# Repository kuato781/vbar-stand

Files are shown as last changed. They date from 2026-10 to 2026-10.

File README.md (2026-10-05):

# Folding Indexed Stand for the VBar Transmitter

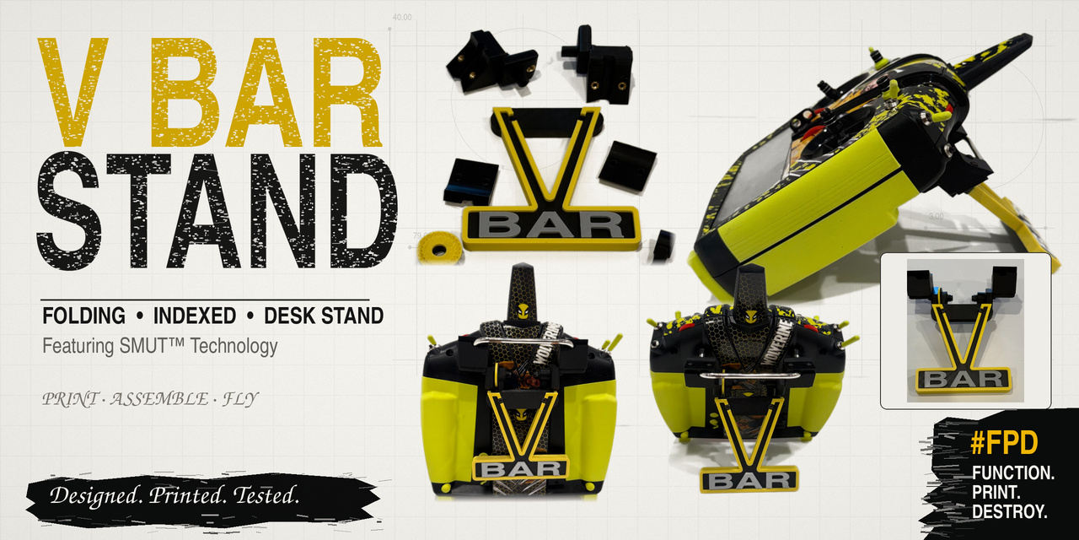
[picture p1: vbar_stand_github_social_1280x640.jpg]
VBar stand


A folding, indexed-position desk stand for the VBar transmitter's curved metal carrying handle. The handle clamps are shaped for this radio; the two retained pivots and right-side spring-ball detent follow the proven **SMUT™** (**S**ide **M**ount **U**nit **T**echnology) architecture from the [iX14](https://github.com/kuato781/spektrum-ix14-stand) and [Spirit WAVE](https://github.com/kuato781/spirit-wave-stand) stands.

The stand folds against the back of the transmitter, keeps the carrying handle usable, and indexes into position with a replaceable detent ring. It mounts without permanently modifying the radio.

## Start here

- [Assembly instructions](documentation/assembly-instructions/assembly-instructions.md)
- [Printable three-stage assembly guide](documentation/exploded-view/VBar-assembly-guide.pdf)
- [Hardware buy list](buy-list/VBar-Stand-Buy-List.md)
- [Bambu Studio notes](bambu-studio-3mf/bambu-studio-profile.md)
- [Individual STL and SCAD files](stl-scad/)
- [Product photos](documentation/product-images/)

Ready-to-slice Bambu Studio projects are available for the [mounting hardware](bambu-studio-3mf/mounting-hardware/Vbar_all_mounting_hardware.3mf) and the [three-color stand](bambu-studio-3mf/stand/VBar-Stand.3mf). The ten individual STLs are also in `stl-scad/`.

## The VBar-specific fit

The handle rises at an unusual angle, so both case bodies and their matching caps follow the measured handle path. The channel was adjusted during physical fitting until the two sides held the stand square to the transmitter. The final clamp has a left and a right body **and** a left and a right cap; these are not interchangeable common caps.

**Left and right mean looking at the front of the radio.** A shallow `L` or `R` is etched into each matching case/cap. Those letters face **inward toward the middle of the handle** when installed.

The stand/header uses **40 mm pivot-mount centers**, a keyed block at each pivot, and a 66 × 18 × 7 mm header envelope. The replaceable detent ring and M4 spring-loaded ball plunger are on the **right** side.

The V/BAR stand is split into three aligned color parts:

1. `VBar-SMUT-Stand-HEADER-CORE.stl` - structural core and header;
2. `VBar-SMUT-Stand-WRAP.stl` - raised V and outside-edge wrap;
3. `VBar-SMUT-Stand-BAR.stl` - raised BAR lettering.

The pictured build uses a black core, yellow V/wrap, and silver BAR lettering. Import the three STLs **together as parts of one object at their shared origin** if building your own multicolor slice. The header is already included in the core; it is not an extra print.

## Important assembly notes

- Use **four M3 × 10 mm cap screws** (two per side). The Spirit WAVE instructions' M3 × 12 mm length does not apply here.
- Apply a **thin strip of double-sided tape to the tops of the handle** at the clamp locations before fitting the caps. Keep it narrow and away from the controls. The tested build used this to remove a little wiggle.
- Snug the cap screws enough to locate the clamps. The case/cap assemblies can still feel loose at this stage; the keyed stand/header squares and locks the two sides together.
- While tightening the stand mounting screws, **push the stand downward** so the header clears the lower corner of each case. Cycle the full folding motion afterward and confirm clearance on both sides.
- A visible gap at the cap/body seam is expected. Clamp securely without trying to force the halves flush.

The [assembly instructions](documentation/assembly-instructions/assembly-instructions.md) give the full sequence, insert locations, pivot hardware, and plunger adjustment.

## Product photos

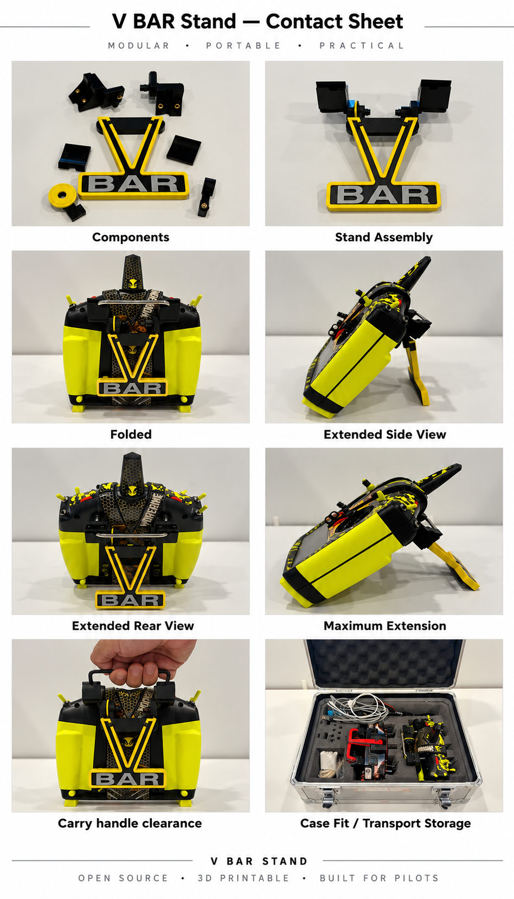
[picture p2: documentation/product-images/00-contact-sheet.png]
VBar stand parts and completed assembly


These are photographs of the actual printed parts and radio: [components](documentation/product-images/01-components.jpg), [assembled](documentation/product-images/02-assembled.jpg), [folded](documentation/product-images/03-folded.jpg), [extended](documentation/product-images/05-extended.jpg), and [mechanical clearance](documentation/product-images/08-clearance.jpg). Additional side and transport views are in the [product-image directory](documentation/product-images/).

## Print files and source

The mounting-hardware 3MF and stand 3MF are separate so each can be printed or reprinted independently. The stand 3MF preserves the aligned multicolor parts. Review printer, build plate, material mapping, orientation, and sliced preview before printing.

Each final STL has a matching SCAD in `stl-scad/`. The SCAD files default to the exact final mesh. The three stand pieces additionally share editable OpenSCAD dimensions in `_vbar_stand_geometry.scad`; the clamp/pivot pieces are mesh-backed because the final case bodies combine measured clamp geometry with remeshed donor pivots. See [SCAD and STL notes](stl-scad/README.md) for what can be changed natively and for the original CadQuery build source.

The development loop was **measure → model → print → fit → revise**. The final parts shown here were physically printed and fitted. PETG was used for the documented build; verify your own prints, hardware and motion before relying on them.

## Repository map

| Path | Contents |
| --- | --- |
| `bambu-studio-3mf/` | Prepared mounting-hardware and multicolor stand projects, plus print notes |
| `buy-list/` | Inserts, screws, plunger, and other assembly supplies |
| `documentation/assembly-instructions/` | Detailed assembly sequence |
| `documentation/exploded-view/` | Printable three-stage guide and page images |
| `documentation/product-images/` | Photos of the physical build |
| `stl-scad/` | Ten final STL/SCAD pairs, stand assembly preview and source notes |

## Safety, affiliation and license

This is a desk/simulator stand, **not a replacement carrying handle**. Inspect parts, heat-set inserts and screws regularly, and confirm motion and stability before use. Read the [disclaimer](DISCLAIMER.md).

This independent community project is not affiliated with or endorsed by Mikado Model Helicopters. VBar and associated names and marks identify the compatible transmitter and remain with their respective owners.

The files are shared under [Creative Commons Attribution-NonCommercial 4.0 International](LICENSE): noncommercial copying, printing and modification with attribution and identification of changes. Commercial use requires separate permission from the creator.

AI assisted with the modeling and documentation through many print-and-fit iterations. The printer and the actual radio got the final vote. :-)

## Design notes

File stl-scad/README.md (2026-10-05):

# Final VBar STL and SCAD Parts

The ten final STL files and ten same-name SCAD files sit side by side in this directory. Open the SCAD in OpenSCAD from a downloaded copy of the entire directory so its neighboring STL resolves by relative filename. The stand preview and `_vbar_stand_geometry.scad` are additional source/helper files.

| Part group | Files | Notes |
| --- | --- | --- |
| Handle clamp | Left/right body and matching left/right cap | Four separate parts; shallow `L`/`R` marks face inward on the radio |
| Pivot mechanism | Left/right pivot stub and detent ring | Ring and spring-ball detent are on the right |
| V/BAR stand | HEADER-CORE, WRAP, BAR | Import all three STLs at one shared origin for color printing |

All per-part SCAD files load their **exact final STL by default**. The three stand SCADs can also generate an editable OpenSCAD reconstruction: set `exact_mesh=false` and change dimensions in `_vbar_stand_geometry.scad`. Font shaping and offset tessellation may differ from the fit-tested STL, so validate a regenerated part before printing it.

The clamp bodies were built from a measured handle path joined to the proven pivot donor with voxel mesh operations. The stubs and ring are carried-forward donor meshes. Their SCADs contain `add_material()` and `remove_material()` hooks for local boolean changes to the exact final mesh; their base shapes are not fully parametric OpenSCAD primitives. This distinction is deliberate.

The [stand assembly preview](VBar-SMUT-stand-assembly-preview.scad) displays the three aligned parts in color. For printing, use the individual STLs or the prepared [stand 3MF](../bambu-studio-3mf/stand/VBar-Stand.3mf). Do not import the three STLs as independently centered objects.

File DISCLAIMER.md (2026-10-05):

# Use at Your Own Risk

The models, print profiles, instructions, photos and other materials in this repository are provided for personal, noncommercial use **as is**. No warranty or representation is made that they are accurate, complete, safe, suitable for a particular purpose or compatible with a particular printer, material or transmitter revision.

3D-printed parts vary with calibration, filament, slicer settings, print orientation, layer bonding, heat-set technique, fastener tolerances, use and wear. Review the files and hardware; inspect every print and insert; verify fit and pivot motion on your own radio; test on a stable surface; and reinspect the assembly periodically. Replace cracked, deformed or worn parts.

This is a desk/simulator stand, **not a replacement carrying handle**. The installed stand changes the radio's external dimensions; check any transport case for clearance before closing it. Never force a fold, pivot or latch through an obstruction. Independently verify anything that could affect control or safe operation of the transmitter.

By downloading, printing, modifying, assembling or using these materials, you accept the associated risks, including damage to equipment or property and personal injury. The parts are not professionally engineered, certified or tested as safety equipment. To the maximum extent permitted by law, the creator and contributors are not liable for losses arising from their use or inability to be used.

If you modify or redistribute the files, identify your changes and validate your version. Preserve this disclaimer or provide an equivalent notice. This independent project is not affiliated with or endorsed by Mikado Model Helicopters; VBar and related names and marks remain with their respective owners.

This disclaimer supplements the [LICENSE](LICENSE); if they conflict, the license controls.

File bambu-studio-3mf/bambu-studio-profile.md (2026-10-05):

# Bambu Studio Notes - VBar Stand

The repository contains separate prepared projects:

- [Vbar_all_mounting_hardware.3mf](mounting-hardware/Vbar_all_mounting_hardware.3mf)
- [VBar-Stand.3mf](stand/VBar-Stand.3mf)

The mounting hardware can be reprinted independently of the three-color stand. The documented physical build uses PETG. Choose a suitable PETG profile for your printer and filament, then verify the selected machine, plate, nozzle and filament mapping before slicing.

## Stand color parts

The stand comprises three aligned objects: black structural core/header, colored V and edge wrap, and BAR lettering. The photographed build uses yellow for the wrap and silver for the letters. Preserve their shared origin when importing the individual STLs; do not center each part separately.

The black core already includes the keyed header. The stand project is the simplest way to retain the intended color separation.

## Before printing

- Inspect the sliced preview for missing regions, unexpected supports, color changes and gaps.
- Confirm that cap holes, pivot sleeves, keyed blocks and the M4 plunger insert bore print cleanly.
- Confirm that the stand's black core, V wrap and letters remain aligned.
- Check the 3MF's material mapping and printer settings against your own setup; do not assume those settings transfer automatically.

## Fit-sensitive details

- Left/right case bodies and caps are distinct. Their shallow `L` and `R` marks face the inside of the handle when viewed from the front of the radio.
- Use the VBar's **M3 × 10 mm cap screws**.
- A thin double-sided tape strip on top of the handle helps remove play before the caps are fitted.
- The clamped halves can feel a little loose until the stand/header joins and squares both sides. A small cap/body gap is expected.
- During final tightening, press the stand downward to ensure its header clears the bottom case corners, then cycle the full range of motion.

Follow the [assembly instructions](../documentation/assembly-instructions/assembly-instructions.md) and verify the fit of your printed parts on your own radio.

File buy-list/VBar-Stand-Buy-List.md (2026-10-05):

# VBar Stand - Hardware Buy List

This VBar implementation uses the retained-pivot and detent hardware proven on the iX14 and Spirit WAVE stands, with **M3 × 10 mm cap screws** for the VBar-specific clamps.

## Heat-set inserts

- [ ] **6 × M3 inserts**, approximately **5 mm outside diameter × 5 mm long** - four in the case bodies for cap screws, one in each pivot-stub stand block
- [ ] **1 × M4 insert**, approximately **6 mm outside diameter × 6 mm long** - right case body for the ball plunger

## Pivot and detent hardware

- [ ] **1 × M4 × 0.7 spring-loaded ball plunger**, approximately 8-9 mm threaded body with an approximately 2.5 mm ball (tested spring range: 3-15 N)
- [ ] **2 × M4 × 20 mm socket-head or button-head screws**
- [ ] **2 × M4 Nyloc nuts**
- [ ] **2 × M4 flat washers**

## Clamp and stand hardware

- [ ] **4 × M3 × 10 mm socket-head or button-head screws** - two for each case cap
- [ ] **2 × M3 × 8 mm button-head screws** - keyed stand/header mounts
- [ ] **2 × M3 flat washers** - stand mounting screws

## Assembly supplies

- [ ] **Thin double-sided tape**, one narrow strip on top of the handle at each clamp location
- [ ] Optional: a small amount of **removable, non-permanent threadlocker** for the ball-plunger threads

The two caps are different left/right parts. A shallow `L`/`R` on each cap and body faces inward when mounted, as seen from the front of the radio. Do not substitute the Spirit WAVE's M3 × 12 mm cap screws.

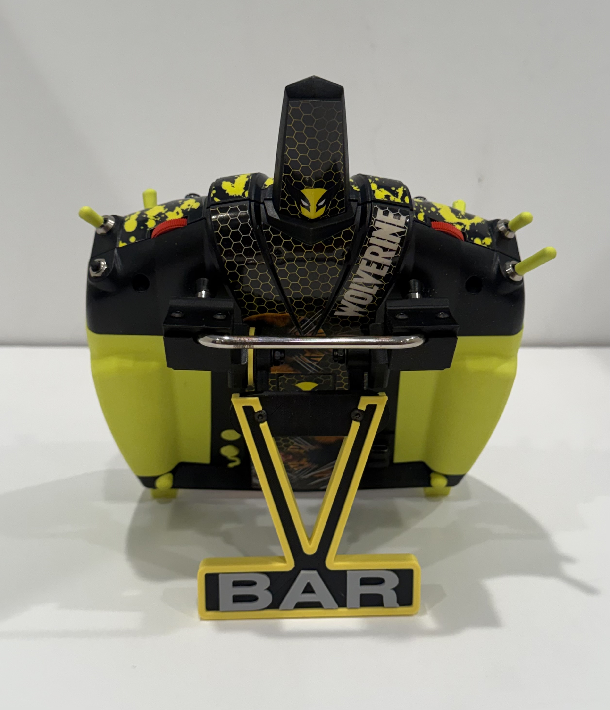
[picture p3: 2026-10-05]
documentation/product-images/05-extended.jpg

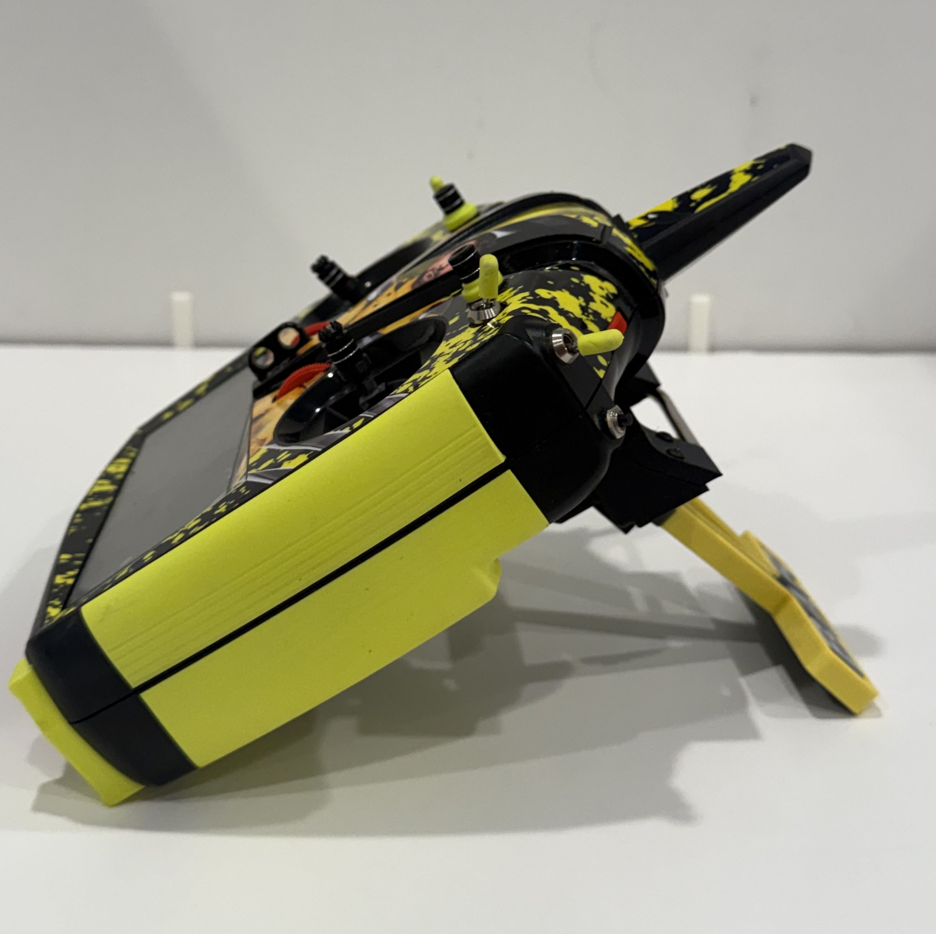
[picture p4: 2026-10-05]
documentation/product-images/07-extended_side_max.jpg

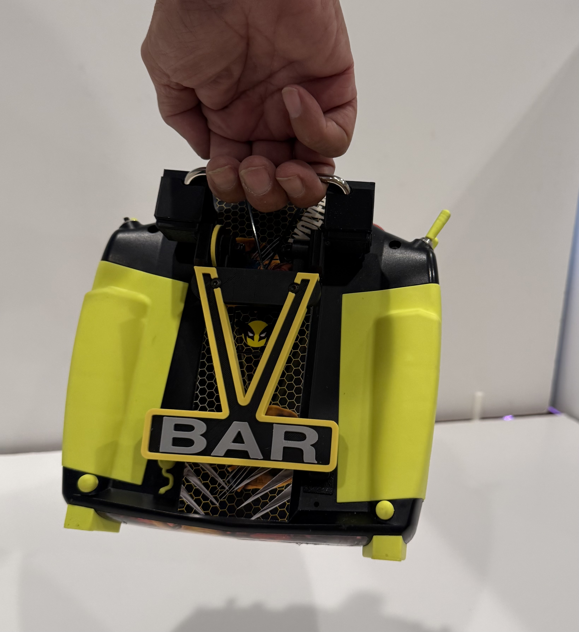
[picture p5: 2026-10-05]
documentation/product-images/08-clearance.jpg

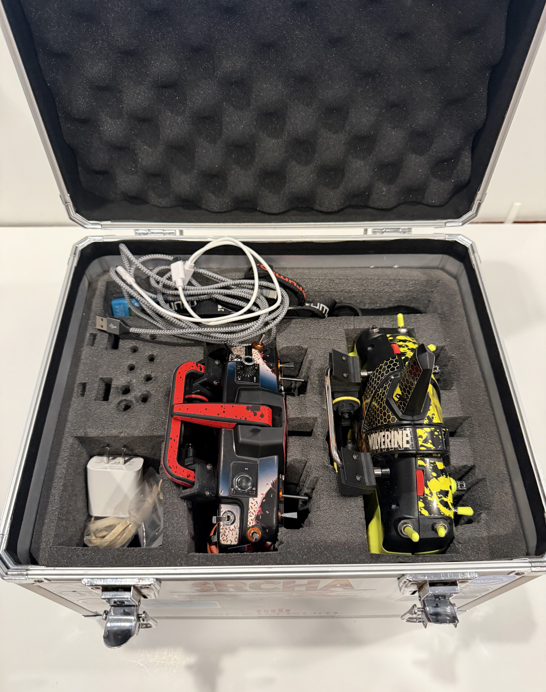
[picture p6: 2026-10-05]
documentation/product-images/10-carrier-fir.jpg

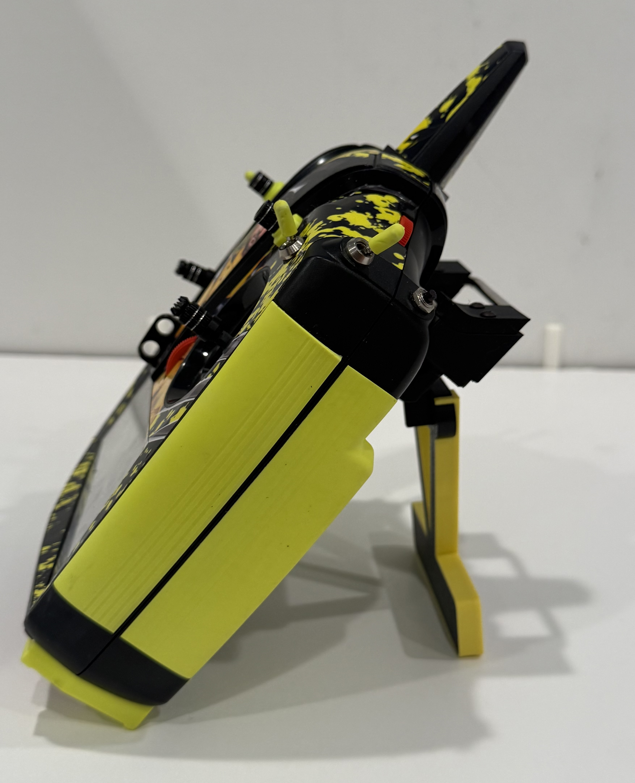
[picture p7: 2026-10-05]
documentation/product-images/04-extended_side.jpg

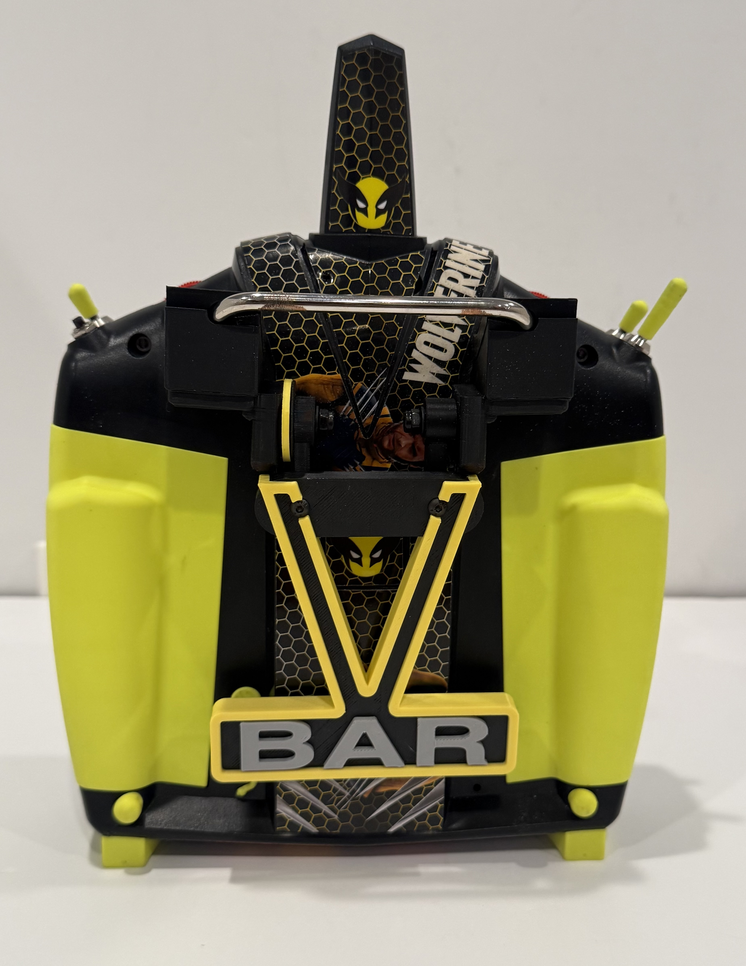
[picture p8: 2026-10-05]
documentation/product-images/03-folded.jpg

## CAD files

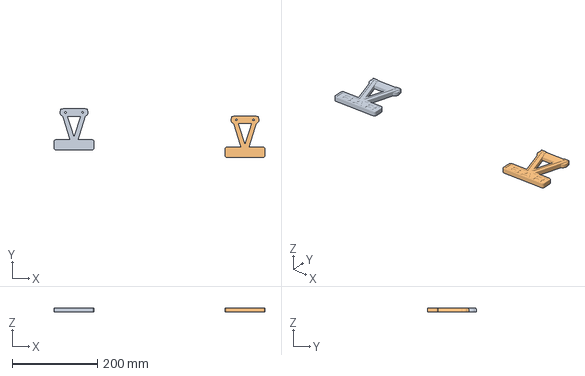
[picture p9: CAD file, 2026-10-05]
bambu-studio-3mf/stand/VBar-Stand.3mf
495.0 x 114.4 x 9.00 mm
VBar-SMUT-Stand x 2

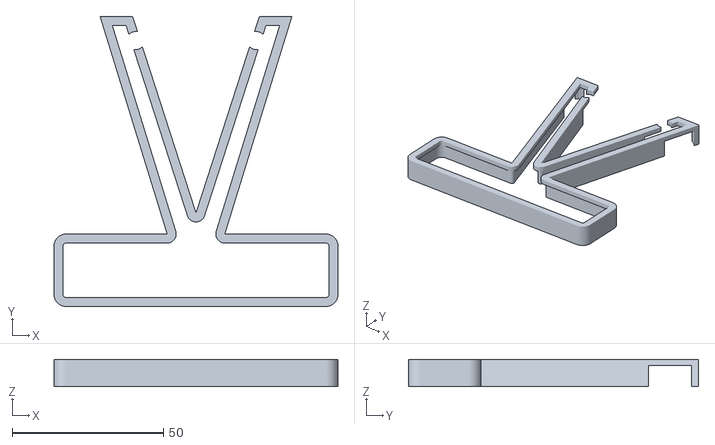
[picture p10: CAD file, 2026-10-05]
stl-scad/VBar-SMUT-Stand-WRAP.stl
94.0 x 96.0 x 9.00

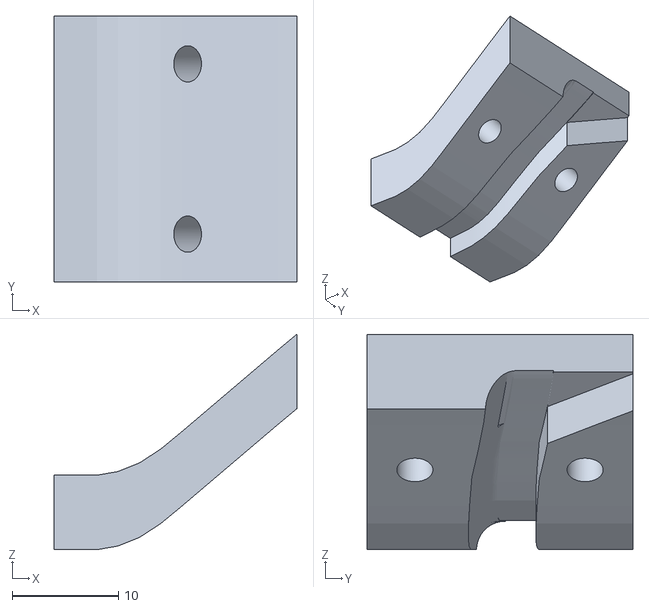
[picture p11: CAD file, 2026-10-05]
stl-scad/VBar-SMUT-right-cap.stl
22.8 x 25.0 x 20.2

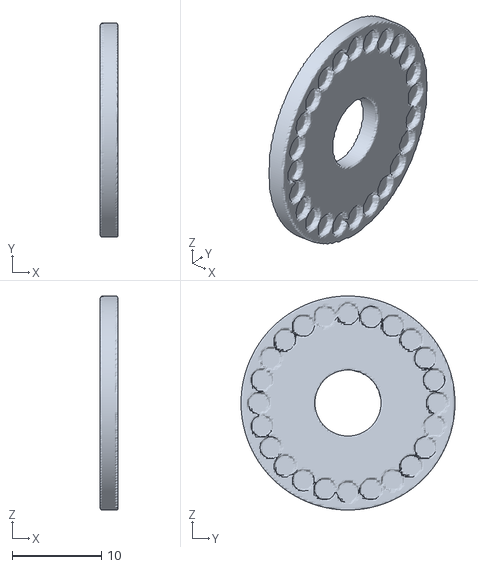
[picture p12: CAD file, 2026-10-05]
stl-scad/VBar-SMUT-detent-ring.stl
2.00 x 24.0 x 24.0

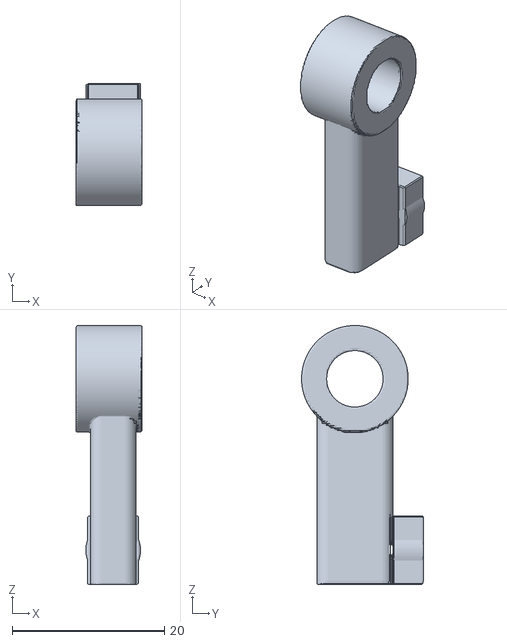
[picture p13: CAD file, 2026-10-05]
stl-scad/VBar-SMUT-left-pivot-stub.stl
8.70 x 16.0 x 34.0

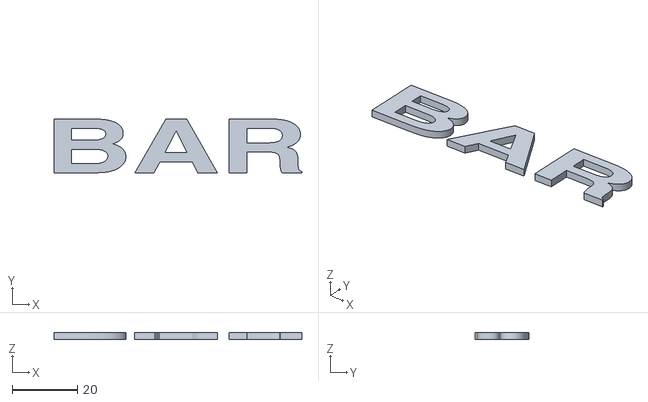
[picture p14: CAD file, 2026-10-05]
stl-scad/VBar-SMUT-Stand-BAR.stl
76.0 x 16.5 x 2.00

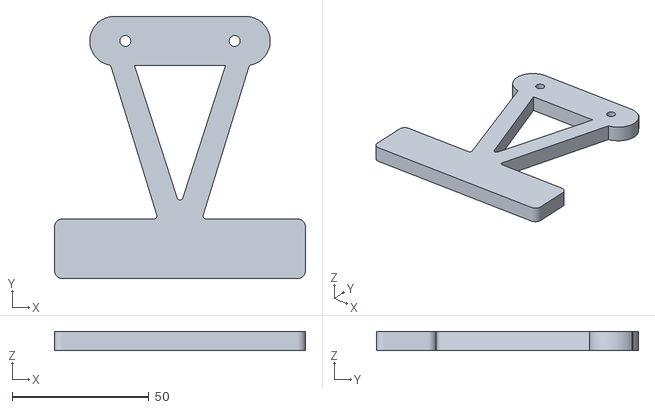
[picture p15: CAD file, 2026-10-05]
stl-scad/VBar-SMUT-Stand-HEADER-CORE.stl
91.8 x 95.9 x 7.00

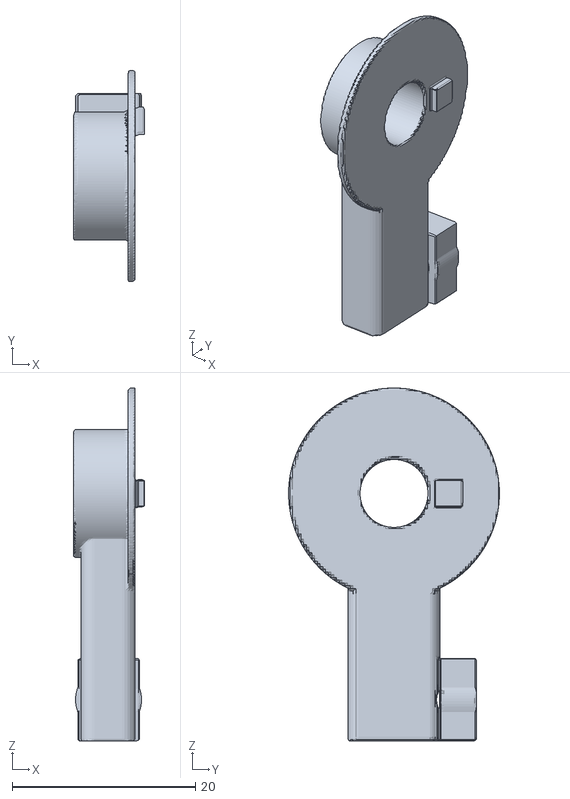
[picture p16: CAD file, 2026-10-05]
stl-scad/VBar-SMUT-right-pivot-stub.stl
7.70 x 23.0 x 38.5

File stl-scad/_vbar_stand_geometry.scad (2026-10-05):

// VBar SMUT 3.4 stand, OpenSCAD construction (millimetres).
// The delivered STL meshes are the fit-tested authority. This source exposes
// the design's nominal dimensions for revisions; compare any regenerated
// mesh with the supplied reference before printing it.

header_length = 66;
header_width = 18;
header_thickness = 7;
pivot_spacing = 40;
pivot_bore_d = 4;
head_relief_d = 6;
key_x = 8.06;
key_y = 9.36;
key_depth = 4.115;

plate_thickness = 7;
color_rise = 2;
sidewall_rim = 1.10;
front_trim_width = 3;
base_width = 94;
base_bottom_y = -88;
base_top_y = -64;
base_corner_r = 4;
v_tip_y = 8;
bar_width = 76;
bar_height = 16.5;
bar_center_y = -76;

$fn = 96;

function v_outer_tip() = 27 + (v_tip_y + 7.4)*(27-8)/(69-7.4);
function v_inner_tip() = 16 + (v_tip_y + 7.4)*16/(57-7.4);

module capsule_2d() {
    hull() {
        translate([-(header_length-header_width)/2, 0]) circle(d=header_width);
        translate([ (header_length-header_width)/2, 0]) circle(d=header_width);
    }
}

module stand_outline_2d() {
    union() {
        translate([0,(base_bottom_y+base_top_y)/2])
            offset(r=base_corner_r)
                square([base_width-2*base_corner_r,
                        base_top_y-base_bottom_y-2*base_corner_r], center=true);
        polygon(points=[[-v_outer_tip(),v_tip_y],[-8,-69],[8,-69],
                        [v_outer_tip(),v_tip_y],[v_inner_tip(),v_tip_y],
                        [0,-57],[-v_inner_tip(),v_tip_y]]);
    }
}

module stand_rim_2d(width) {
    difference() {
        stand_outline_2d();
        offset(delta=-width) stand_outline_2d();
    }
}

module stand_core() {
    difference() {
        union() {
            linear_extrude(height=plate_thickness)
                difference() {
                    stand_outline_2d();
                    difference() {
                        stand_rim_2d(sidewall_rim);
                        capsule_2d();
                    }
                }
            linear_extrude(height=header_thickness) capsule_2d();
        }
        for (x=[-pivot_spacing/2,pivot_spacing/2]) {
            translate([x-key_x/2,-key_y/2,-0.1])
                cube([key_x,key_y,key_depth+0.1]);
            translate([x,0,-0.1]) cylinder(d=pivot_bore_d,h=header_thickness+0.2);
        }
    }
}

module v_wrap() {
    difference() {
        union() {
            linear_extrude(height=plate_thickness)
                difference() {
                    stand_rim_2d(sidewall_rim);
                    capsule_2d();
                }
            translate([0,0,plate_thickness])
                linear_extrude(height=color_rise)
                    stand_rim_2d(front_trim_width);
        }
        for (x=[-pivot_spacing/2,pivot_spacing/2])
            translate([x,0,plate_thickness-0.01])
                cylinder(d=head_relief_d,h=color_rise+0.02);
    }
}

module bar_letters() {
    // Exact fonts and tessellation can vary across OpenSCAD installations.
    translate([0,bar_center_y,plate_thickness])
        linear_extrude(height=color_rise)
            resize([bar_width,bar_height])
                text("BAR",size=25,font="Nimbus Sans Narrow:style=Bold",
                     halign="center",valign="center");
}

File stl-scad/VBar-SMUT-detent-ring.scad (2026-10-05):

// Spirit 0.16 donor carried forward unchanged. Mesh is authoritative.
module add_material() {}
module remove_material() {}
difference() {
    union() {
        import("VBar-SMUT-detent-ring.stl",convexity=10);
        add_material();
    }
    remove_material();
}

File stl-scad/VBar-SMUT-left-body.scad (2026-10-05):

// Mesh-backed final 2.3 body: the donor/handle union was voxel remeshed.
// The final STL is authoritative; local OpenSCAD changes go below.
module add_material() {}
module remove_material() {}
difference() {
    union() {
        import("VBar-SMUT-left-body.stl",convexity=10);
        add_material();
    }
    remove_material();
}

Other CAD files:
stl-scad/VBar-SMUT-left-cap.stl
stl-scad/VBar-SMUT-left-cap.scad
stl-scad/VBar-SMUT-Stand-BAR.scad
stl-scad/VBar-SMUT-Stand-HEADER-CORE.scad
stl-scad/VBar-SMUT-Stand-WRAP.scad
stl-scad/VBar-SMUT-left-pivot-stub.scad
stl-scad/VBar-SMUT-right-body.scad
stl-scad/VBar-SMUT-right-cap.scad
stl-scad/VBar-SMUT-right-pivot-stub.scad
stl-scad/VBar-SMUT-stand-assembly-preview.scad

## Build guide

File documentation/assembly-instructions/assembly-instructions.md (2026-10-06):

# VBar Stand - Assembly Instructions

[Download the printable three-stage guide (PDF)](../exploded-view/VBar-assembly-guide.pdf)

This is the VBar implementation of **SMUT™** - **S**ide **M**ount **U**nit **T**echnology. Separate left and right case assemblies clamp around the radio's curved carrying handle. Retained pivots connect them to the keyed V/BAR stand; the right pivot carries a replaceable detent ring and spring-loaded ball plunger.

**Left and right are always described while looking at the front of the radio.** Each body and its matching cap has a shallow `L` or `R`. The letters face **toward the inside of the handle**, not toward the outside edge of the transmitter. The caps are distinct left and right parts.

## Files and printed parts

For Bambu Studio, use the [mounting-hardware 3MF](../../bambu-studio-3mf/mounting-hardware/Vbar_all_mounting_hardware.3mf) and [stand 3MF](../../bambu-studio-3mf/stand/VBar-Stand.3mf). The ten final individual [STLs and matching SCADs](../../stl-scad/) are also provided. If importing stand STLs yourself, load the core, V wrap and BAR letters as aligned parts of one object.

| Quantity | Part |
| ---: | --- |
| 1 each | Left and right case body |
| 1 each | Matching left and right cap |
| 1 each | Left plain and right detent pivot stub |
| 1 | Replaceable detent ring (right side) |
| 1 assembly | V/BAR stand (structural core, colored V wrap, BAR letters) |

The stand's keyed header is already part of its structural core. It is **not** an additional printed component.

Use the [VBar hardware buy list](../../buy-list/VBar-Stand-Buy-List.md) for quantities and sizes. In particular, the four cap screws are **M3 × 10 mm**, not the M3 × 12 mm screws used on the Spirit WAVE.

## Before mounting: heat-set inserts

Install the inserts while the pieces are off the radio, using an aligned heat-set tool. Allow the plastic to cool completely before threading hardware into it.

- **4 × M3 inserts:** two cap-screw bores in each case body.
- **2 × M3 inserts:** one in each pivot stub's square stand-mounting block.
- **1 × M4 insert:** spring-ball-plunger bore in the right detent case body.

Check the printed M4 collar before pressing its insert. Clean up a rough opening lightly if necessary without enlarging the bore more than needed. Do not mistake the M3 cap-screw insert for the larger M4 plunger insert.

## Stage 1 - Build the left and right pivot assemblies

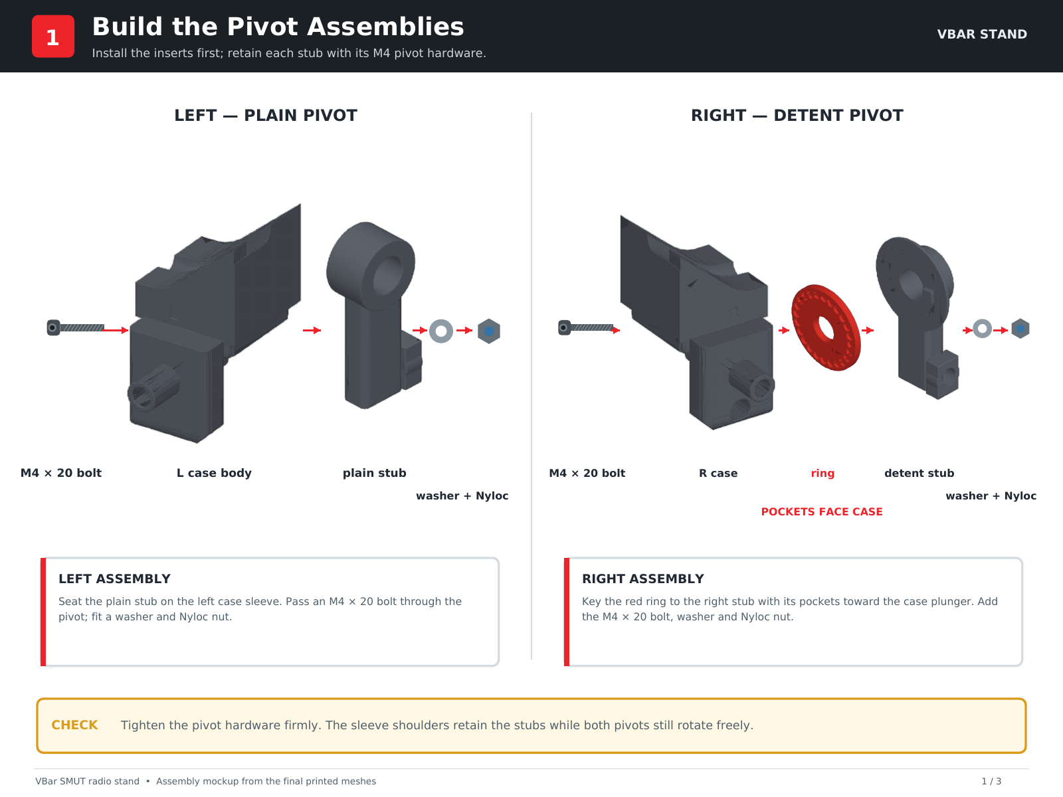
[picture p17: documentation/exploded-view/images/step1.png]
Illustrated Stage 1: VBar case bodies, pivot stubs, ring and hardware


1. Identify the **right** case body, right detent pivot stub and replaceable detent ring. Seat the ring on the stub's keyed support face, aligning the asymmetric key. Its detent pockets must face the right case body's ball-plunger bore.
2. Slide the right pivot stub onto the right case body's pivot sleeve. Install an **M4 × 20 mm** pivot screw, M4 washer and M4 Nyloc nut.
3. Tighten the pivot hardware firmly. The sleeve shoulder should keep the stub free to rotate; the pivot must not depend on a loose screw for movement.
4. Assemble the left plain pivot stub to the **left** case body in the same way, with the second M4 × 20 screw, washer and Nyloc nut. The left has no detent ring.
5. Confirm both pivots rotate smoothly and the right ring remains fully keyed.

## Stage 2 - Fit the VBar handle clamps

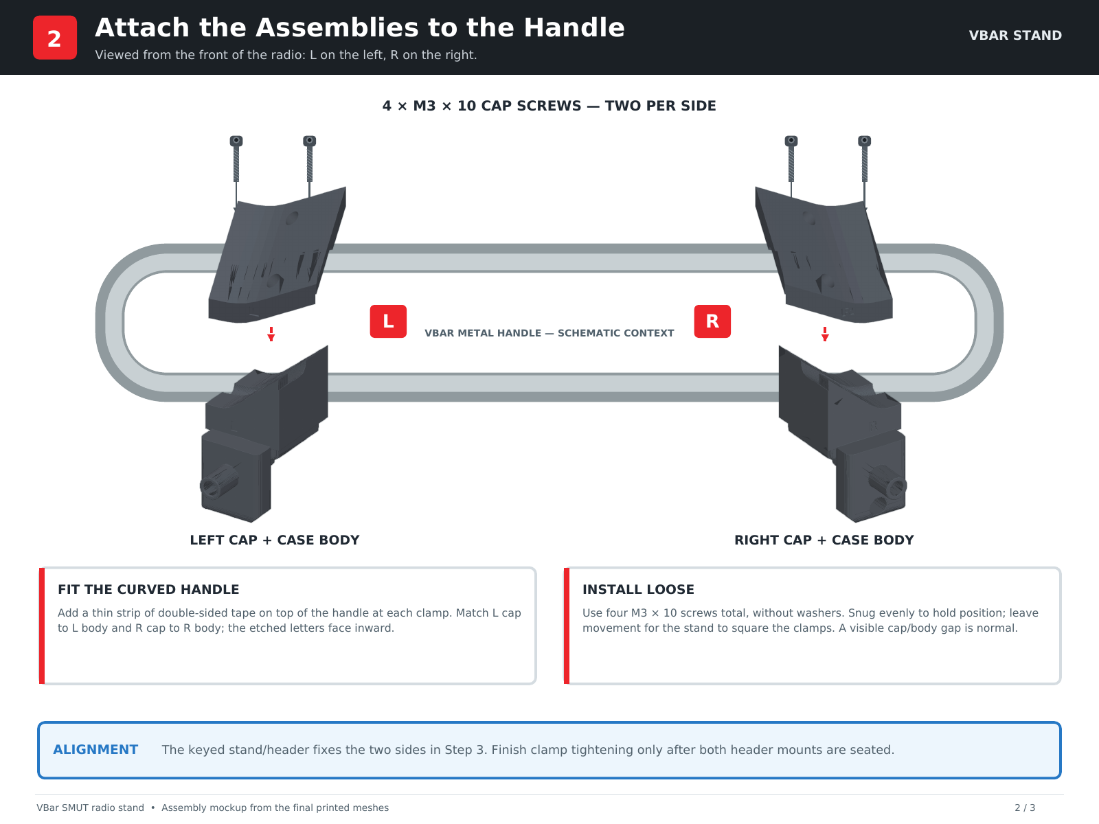
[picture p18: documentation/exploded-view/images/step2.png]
Illustrated Stage 2: VBar cap and case assemblies around the handle


1. Clean the two clamp locations on the metal handle. Apply a **thin, narrow strip of double-sided tape to the top of the handle** at each location. Keep the tape clear of the controls and visible handle opening.
2. Place each case body at its matching left/right location on the curved handle. Seat the handle in the shaped channel.
3. Match the **left cap to the left body** and the **right cap to the right body**. As viewed from the front, the shallow `L` and `R` marks on the cap and body face the **inside** of the handle.
4. Install **two M3 × 10 mm screws through each cap**. No washer is required under the cap screws. Tighten evenly only enough to hold the assemblies in position for the stand/header fit.

At this point the halves may feel a little wiggly even though the channel and screws are seated. That is expected on the tested build: the stand/header joins and squares the two sides. A cap-to-body gap is normal. Do not force the seam closed just to remove the visible gap.

## Stage 3 - Attach, square and tighten the V/BAR stand

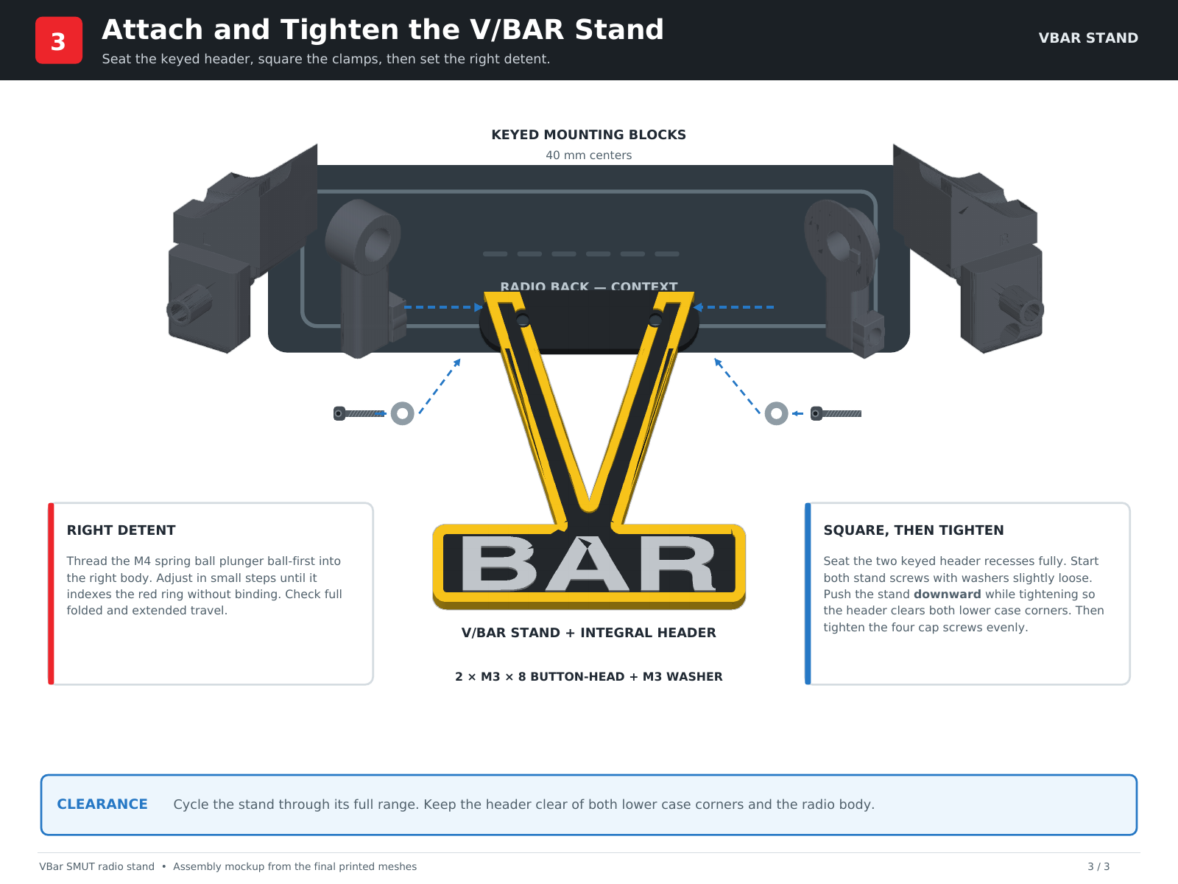
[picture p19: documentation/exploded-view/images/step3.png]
Illustrated Stage 3: V/BAR stand and keyed pivot mounts


1. Align the stand/header's two keyed recesses with the square mounting blocks on the pivot stubs. The centers are **40 mm apart**. Seat both blocks fully; the keys carry the twisting and shear loads.
2. Insert one **M3 × 8 mm button-head screw and M3 washer** at each header mount into the pivot block's M3 insert. Leave both stand screws slightly loose while aligning.
3. Bring the two handle clamps square and parallel with the header. Push the stand **downward as you tighten its mounting screws** so the header clears the **lower corner of each case body**.
4. Tighten the four M3 × 10 cap screws evenly until the clamps grip the handle securely. Keep the left/right body and cap aligned; a visible seam gap is acceptable. Then finish tightening both stand screws while maintaining the downward clearance.
5. Fold and deploy the stand through its complete travel. Check both lower case corners, the radio body and controls for rubbing or binding. If the header catches, stop and correct the alignment before using the stand.

## Set the right-side ball plunger

1. If desired, apply a tiny amount of **removable, non-permanent threadlocker** to the M4 insert threads using an awl or similar small tool. Keep it off the plastic and out of the plunger mechanism.
2. Insert the M4 × 0.7 spring-loaded ball plunger **ball end first** through its access bore and thread it into the right case body's M4 insert.
3. Adjust in small increments while folding and extending the stand. Stop when the ball seats positively in the ring's detents without making the pivot difficult to move.
4. Cycle repeatedly, confirming the ring stays fully seated and the plunger catches each intended position. Never use permanent threadlocker here.

## Final check

- `L`/`R` case bodies and caps match their respective sides and their letters face inward.
- The thin tape strips are under the tops of the handle at the clamp locations.
- All four M3 × 10 cap screws grip securely; the cap/body gaps need not close flush.
- Both M4 pivot screws, washers and Nyloc nuts are secure; both stubs rotate freely.
- The detent ring key is seated and its pockets face the right-side plunger.
- Both keyed stand blocks are fully seated and retained by M3 × 8 screws and washers.
- The stand/header clears both lower case corners throughout folding and extension.
- The ball plunger engages deliberately without binding or damaging the ring.
- The stand supports the radio on a stable desk and folds clear of controls and bodywork.
- The carrying handle remains usable; check transport-case fit separately.

Inspect the parts and hardware again after the first several use cycles and periodically thereafter. This is a desk/simulator stand, **not a replacement carrying handle**. See the [disclaimer](../../DISCLAIMER.md).

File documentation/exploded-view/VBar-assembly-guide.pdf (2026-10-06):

1

# Build the Pivot Assemblies

Install the inserts first; retain each stub with its M4 pivot hardware.

VBAR STAND

LEFT — PLAIN PIVOT | RIGHT — DETENT PIVOT

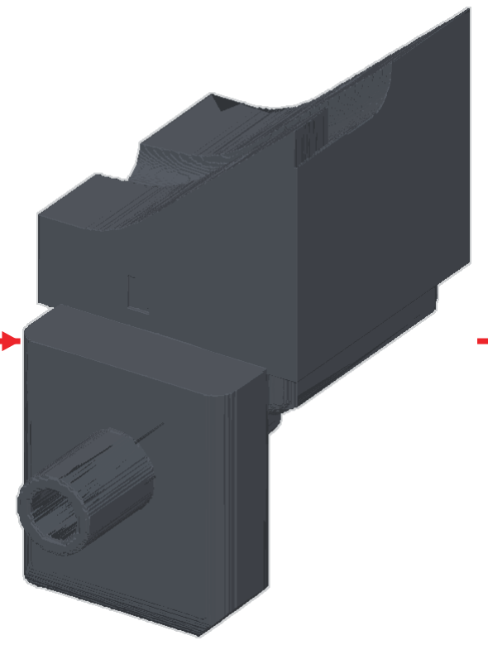
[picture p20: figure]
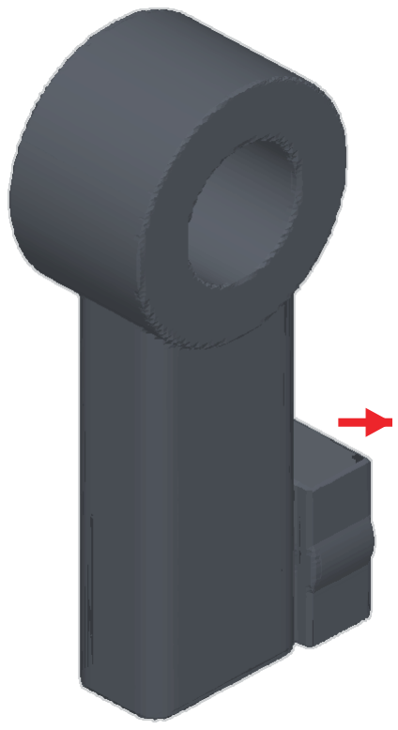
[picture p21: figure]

M4 × 20 bolt | L case body | plain stub

washer + Nyloc

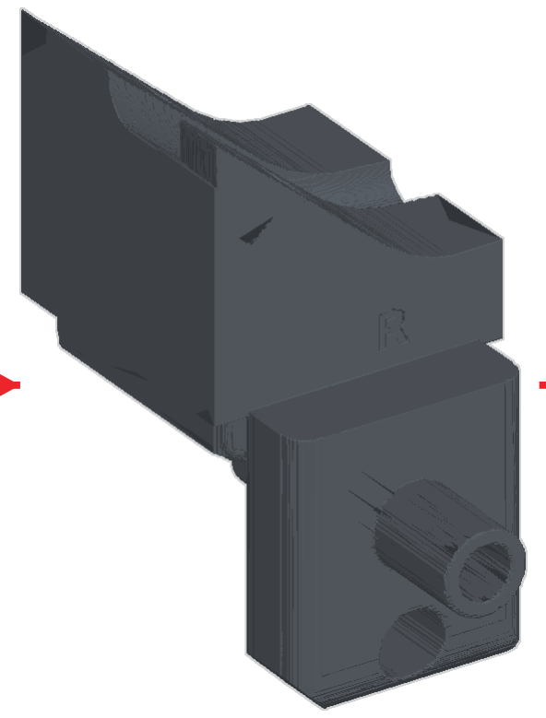
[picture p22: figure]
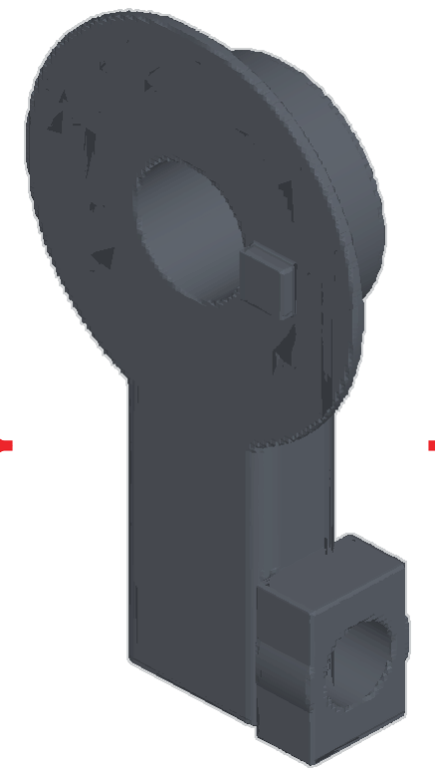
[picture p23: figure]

M4 × 20 bolt | R case | ring | detent stub
| | | washer + Nyloc
| | POCKETS FACE CASE

LEFT ASSEMBLY

Seat the plain stub on the left case sleeve. Pass an M4 × 20 bolt through the pivot; fit a washer and Nyloc nut.

RIGHT ASSEMBLY

Key the red ring to the right stub with its pockets toward the case plunger. Add the M4 × 20 bolt, washer and Nyloc nut.

CHECK | Tighten the pivot hardware firmly. The sleeve shoulders retain the stubs while both pivots still rotate freely.
VBar SMUT radio stand • Assembly mockup from the final printed meshes | 1 / 3

2

# Attach the Assemblies to the Handle

Viewed from the front of the radio: L on the left, R on the right.

### 4 × M3 × 10 CAP SCREWS — TWO PER SIDE

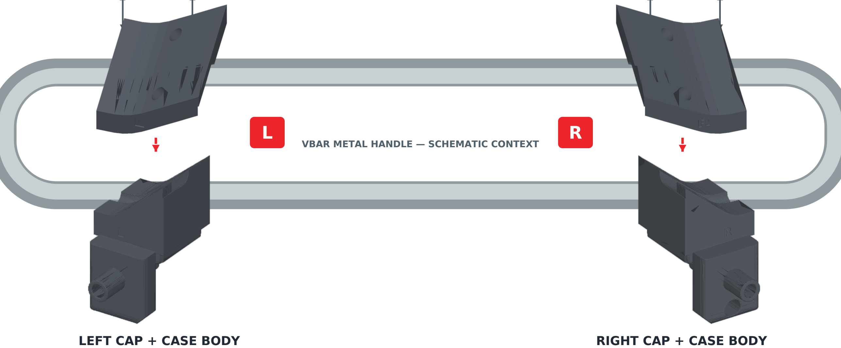
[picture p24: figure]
VBAR METAL HANDLE — SCHEMATIC CONTEXT; LEFT CAP + CASE BODY; RIGHT CAP + CASE BODY

FIT THE CURVED HANDLE

Add a thin strip of double-sided tape on top of the handle at each clamp. Match L cap to L body and R cap to R body; the etched letters face inward.

INSTALL LOOSE

Use four M3 × 10 screws total, without washers. Snug evenly to hold position; leave movement for the stand to square the clamps. A visible cap/body gap is normal.

ALIGNMENT | The keyed stand/header fixes the two sides in Step 3. Finish clamp tightening only after both header mounts are seated.
VBar SMUT radio stand • Assembly mockup from the final printed meshes | 2 / 3

3

# Attach and Tighten the V/BAR Stand

Seat the keyed header, square the clamps, then set the right detent.

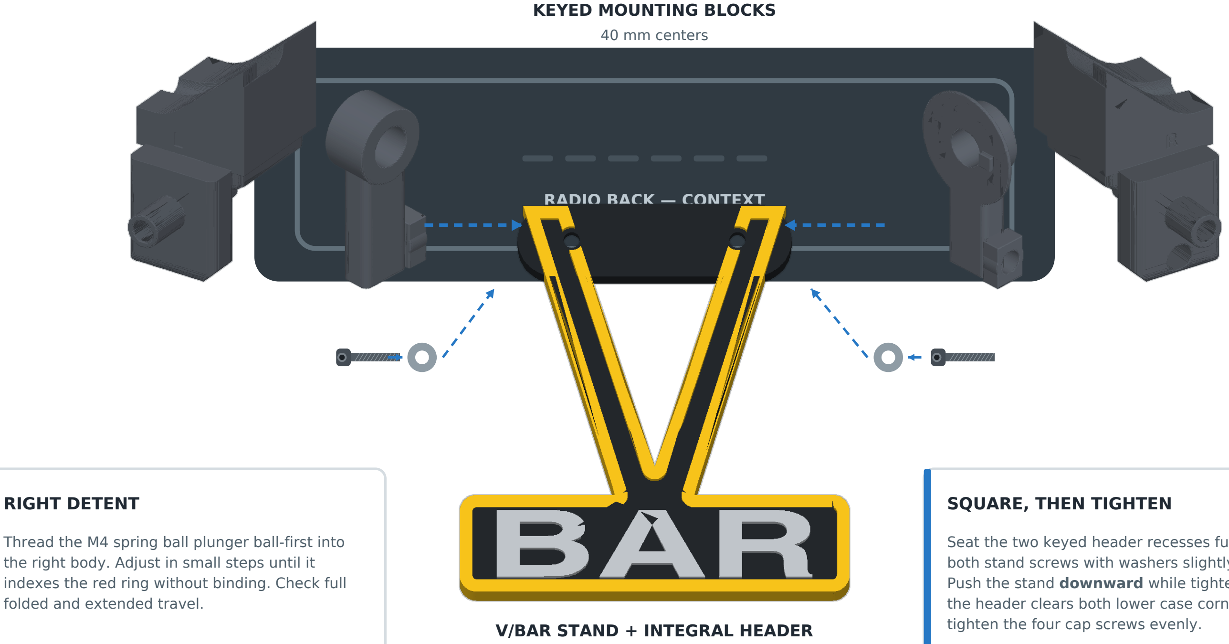
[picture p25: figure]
RADIO BACK — CONTEXT; KEYED MOUNTING BLOCKS; 40 mm centers; V/BAR STAND + INTEGRAL HEADER; SQUARE, THEN TIGHTEN; tighten the four cap screws evenly.; RIGHT DETENT; folded and extended travel.

2 × M3 × 8 BUTTON-HEAD + M3 WASHER

Seat the two keyed header recesses fully. Start both stand screws with washers slightly loose. Push the stand downward while tightening so the header clears both lower case corners. Then

Thread the M4 spring ball plunger ball-first into the right body. Adjust in small steps until it indexes the red ring without binding. Check full

CLEARANCE | Cycle the stand through its full range. Keep the header clear of both lower case corners and the radio body.
VBar SMUT radio stand • Assembly mockup from the final printed meshes | 3 / 3

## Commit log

2026-10-05 File updates
    [VBar-Stand.3mf]
2026-10-05 github social card, stls & scads
    [VBar-SMUT-Stand-BAR.scad, VBar-SMUT-Stand-BAR.stl, VBar-SMUT-Stand-HEADER-CORE.scad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]
2026-10-05 Document VBar stand assembly and correct SCAD paths
    [VBar-SMUT-Stand-BAR.scad, VBar-SMUT-Stand-HEADER-CORE.scad, VBar-SMUT-Stand-WRAP.scad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]
2026-10-06 Replace VBar photo assembly guide with illustrated part mockups
